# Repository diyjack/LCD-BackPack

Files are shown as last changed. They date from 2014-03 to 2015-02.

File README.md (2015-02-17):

# LCD-BackPack
Backpack to control HD44780 compatible displays over UART or I2C.

LCD-BackPack (http://www.watterott.com/en/LCD-BackPack)

## Shop
* [LCD-BackPack](http://www.watterott.com/en/LCD-BackPack)

## Features
* Atmel AVR ATmega328 @ 16 MHz (external resonator)
* Arduino Bootloader (optiboot) with auto baud rate detection
* Serial (UART) and I2C interface
* Single LED and RGB LED backlight support (dimmable)
* Compatible with [SparkFun SerLCD](https://github.com/sparkfun/Serial_Enabled_LCD_Backpack)

## Hardware and Software
* [Schematics + Layout](https://github.com/watterott/LCD-BackPack/tree/master/pcb)
* [Arduino Firmware/Example](https://github.com/watterott/Arduino-Libs/tree/master/LCD_BackPack/examples/SerLCD)

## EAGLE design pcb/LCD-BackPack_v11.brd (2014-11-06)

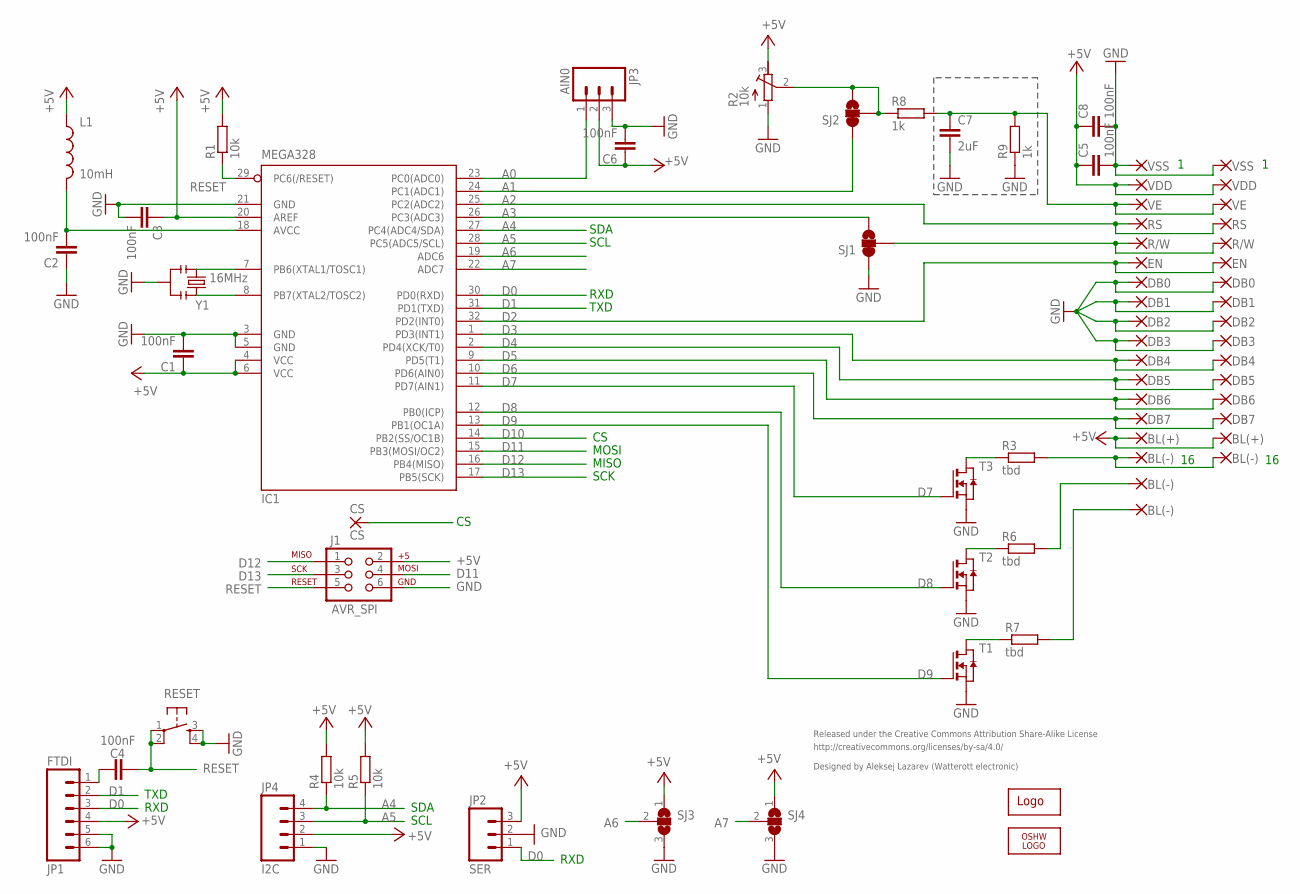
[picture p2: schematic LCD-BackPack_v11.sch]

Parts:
C1, C2, C3, C4, C5, C6, C8: 100nF; C0603
C7: 2uF; C0603
CS: CS; 1,6/0,9
IC1: MEGA328; TQFP32-08
J1: AVR_SPI; 2X3
JP1: FTDI; 1X06
JP2: SER; 1X03
JP3: AIN0; 1X03
JP4: I2C; 1X04
L1: 10mH; 0603
LOGO1: OSHW_LOGO_6MILX0150-NT; OSHW_6X150_NOTEXT
P1, P19: VSS; 1,6/0,9
P2, P20: VDD; 1,6/0,9
P3, P21: VE; 1,6/0,9
P4, P22: RS; 1,6/0,9
P5, P23: R/W; 1,6/0,9
P6, P24: EN; 1,6/0,9
P7, P25: DB0; 1,6/0,9
P8, P26: DB1; 1,6/0,9
P9, P27: DB2; 1,6/0,9
P10, P28: DB3; 1,6/0,9
P11, P29: DB4; 1,6/0,9
P12, P30: DB5; 1,6/0,9
P13, P31: DB6; 1,6/0,9
P14, P32: DB7; 1,6/0,9
P15, P33: BL(+); 1,6/0,9
P16, P17, P18, P34: BL(-); 1,6/0,9
R1, R4, R5: 10k; R0603
R2: 10k; RTRIM3374
R3, R6, R7: tbd; R0603
R8, R9: 1k; R0603
RESET: TAC_SWITCHSMD; TACTILE_SWITCH_SMD
SJ1, SJ2: SOLDERJUMPER_2WAY-OLDS; SJ_3
SJ3, SJ4: SJ2W; SJ_2
T1, T2, T3: NMOSSOT23; SOT-23
U$1: WE-LOGO
Y1: 16MHz; RESONATOR-SMD

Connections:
+5V: C1.1, C3.1, C5.1, C6.1, C8.1, IC1.4 (VCC), IC1.6 (VCC), IC1.20 (AREF), J1.2, JP1.4, JP2.3, JP3.2, JP4.2, L1.1, P2.1, P15.1, P20.1, P33.1, R1.2, R2.3 (A), R4.2, R5.2, SJ3.1, SJ4.1
A0: IC1.23 (PC0(ADC0)), JP3.1
A1: IC1.24 (PC1(ADC1)), SJ2.1
A2: IC1.25 (PC2(ADC2)), P4.1, P22.1
A3: IC1.26 (PC3(ADC3)), SJ1.3
A4: IC1.27 (PC4(ADC4/SDA)), JP4.4, R4.1
A5: IC1.28 (PC5(ADC5/SCL)), JP4.3, R5.1
A6: IC1.19 (ADC6), SJ3.2
A7: IC1.22 (ADC7), SJ4.2
AVCC: C2.2, IC1.18 (AVCC), L1.2
D0: IC1.30 (PD0(RXD)), JP1.3, JP2.1
D1: IC1.31 (PD1(TXD)), JP1.2
D2: IC1.32 (PD2(INT0)), P6.1, P24.1
D3: IC1.1 (PD3(INT1)), P11.1, P29.1
D4: IC1.2 (PD4(XCK/T0)), P12.1, P30.1
D5: IC1.9 (PD5(T1)), P13.1, P31.1
D6: IC1.10 (PD6(AIN0)), P14.1, P32.1
D7: IC1.11 (PD7(AIN1)), T3.3 (G)
D8: IC1.12 (PB0(ICP)), T2.3 (G)
D9: IC1.13 (PB1(OC1A)), T1.3 (G)
D10: CS.1, IC1.14 (PB2(SS/OC1B))
D11: IC1.15 (PB3(MOSI/OC2)), J1.4
D12: IC1.16 (PB4(MISO)), J1.1
D13: IC1.17 (PB5(SCK)), J1.3
GND: C1.2, C2.1, C3.2, C5.2, C6.2, C7.2, C8.2, IC1.3 (GND), IC1.5 (GND), IC1.21 (GND), J1.6, JP1.5, JP1.6, JP2.2, JP3.3, JP4.1, P1.1, P7.1, P8.1, P9.1, P10.1, P19.1, P25.1, P26.1, P27.1, P28.1, R2.1 (E), R9.1, RESET.3, RESET.4, SJ1.1, SJ3.3, SJ4.3, T1.2 (S), T2.2 (S), T3.2 (S), Y1.2
unnamed: R6.1, T2.1 (D)
unnamed: P18.1, R7.2
unnamed: C4.2, JP1.1
unnamed: R3.1, T3.1 (D)
unnamed: P17.1, R6.2
unnamed: R7.1, T1.1 (D)
unnamed: P16.1, P34.1, R3.2
RESET: C4.1, IC1.29 (PC6(/RESET)), J1.5, R1.1, RESET.1, RESET.2
RW: P5.1, P23.1, SJ1.2
VE: C7.1, P3.1, P21.1, R8.2, R9.2
VPOT: R2.2 (S), R8.1, SJ2.2, SJ2.3
XTAL1: IC1.7 (PB6(XTAL1/TOSC1)), Y1.1
XTAL2: IC1.8 (PB7(XTAL2/TOSC2)), Y1.3

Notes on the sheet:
MOSI
MISO
SCK
TXD
RXD
SCL
SDA
Released under the Creative Commons Attribution Share-Alike License
http://creativecommons.org/licenses/by-sa/4.0/
Designed by Aleksej Lazarev (Watterott electronic)

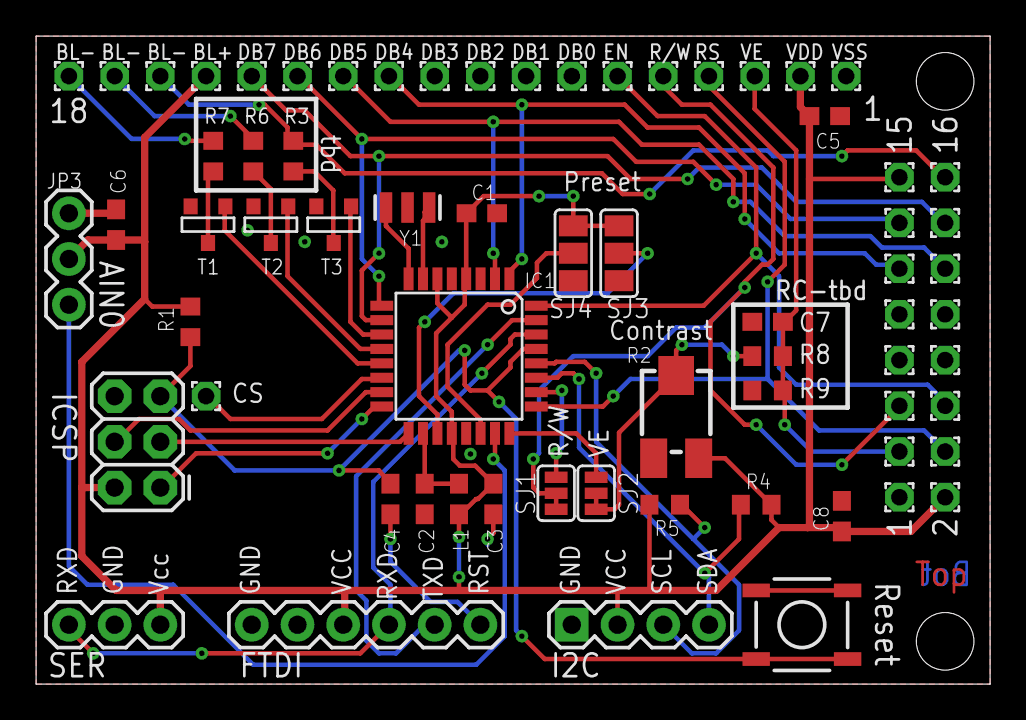
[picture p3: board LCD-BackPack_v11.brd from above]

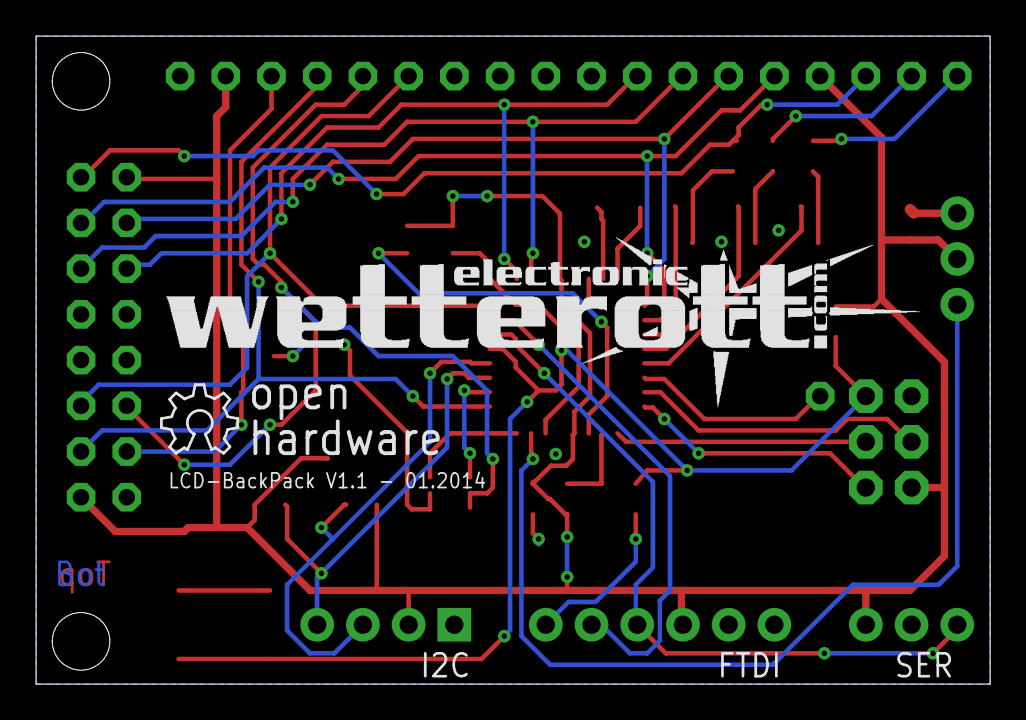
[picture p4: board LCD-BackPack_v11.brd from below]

Board: 2 copper layers, 53.0 x 36.0 mm, 70 parts (2 on the bottom side), 38 nets.

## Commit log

2014-03-10 added schematics and layout files
    [LCD-BackPack_v11.brd, LCD-BackPack_v11.sch]
2014-08-21 updated layout and schematics
    [LCD-BackPack_v11.brd]
2014-11-06 cleaned up schematics and layout
    [LCD-BackPack_v11.brd, LCD-BackPack_v11.sch]

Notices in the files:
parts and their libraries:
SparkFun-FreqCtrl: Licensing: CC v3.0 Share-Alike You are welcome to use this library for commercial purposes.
